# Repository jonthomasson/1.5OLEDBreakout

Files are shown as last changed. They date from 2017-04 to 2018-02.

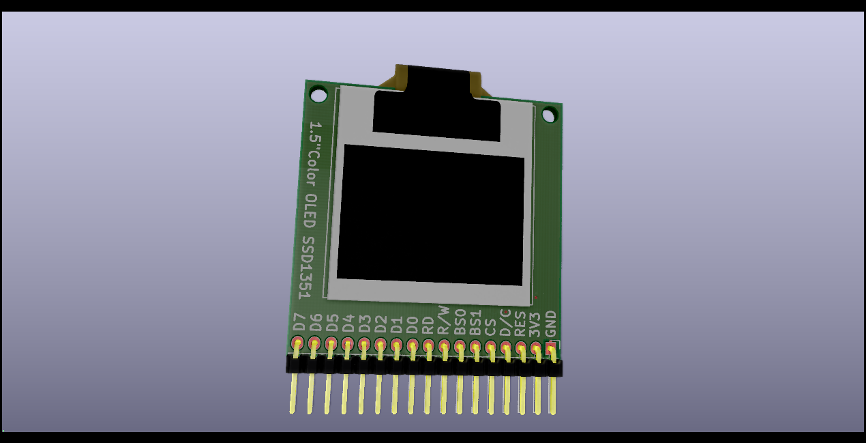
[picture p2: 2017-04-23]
rev1.c/OLED_1.5_128X128_breakout.png

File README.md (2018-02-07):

# 1.5OLEDBreakout
1.5" OLED Breakout SSD1351

Who doesn't love OLED's? Their relatively low power requirements as well as vibrant color displays are alluring to the hacker. While working on a few projects recently I had the need to interface with one of these OLED displays. There didn't seem to be any breakout boards that broke out the parallel interface pins of the controller, so I decided to make my own.

Scouring the internet for a decent OLED display, I came across this one from buydisplay.com. It's a 128x128 RGB display, with 1.5" diagonal measurement. The controller, SSD1351, supports a 8, 16, or 18 bit parallel interface, as well as SPI for communications. It seemed perfect for the projects I had in mind. Most breakout boards out there only take advantage of the SPI pins of the controller, and at least one of my projects would require access to the parallel interface, so I decided to just build my own board to suite my needs. Hopefully someone else finds it useful.

After tying BS0 and BS1 to ground to enable SPI, I tested the OLED with the [adafruit  SSD1351 driver library](https://github.com/adafruit/Adafruit-SSD1351-library).

![OLED Breakout running test program from Adafruit SSD1351 library](https://lh3.googleusercontent.com/MsKkN0FBhNv1MBZHOAWehuTeS2_8jIe-vTxg2sqLBS44pNBJPy4iuyDUc9Usf4BQjBpzPWWo7Bnqe3NkQCG8paahzHArL8N2OJRp6vAqdoAcOqIph1lTVyudKYCDfX7VTnM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)

![enter image description here](https://lh3.googleusercontent.com/N4O0tLOCn0Eo37ZxnNt6EblDyE1QjhN_yxB5joiKvIgpHKnZqY0Tt5LPPp8S8s6vpi8v4A9ziG02BMIxa5gTNILQGj3B6yaHgSGacTQC9WjqcnNdZdKckPPqEXiD1Bdt_oR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)

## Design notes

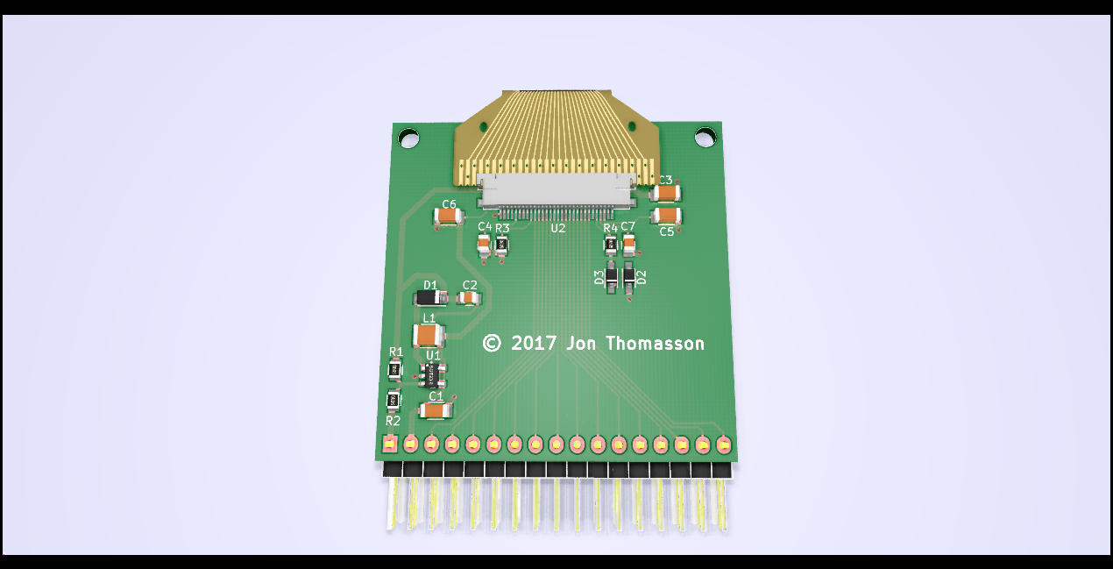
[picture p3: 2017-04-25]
rev1.c/OLED_1.5_128X128_breakout_back.png

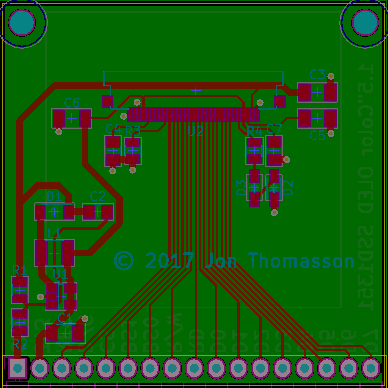
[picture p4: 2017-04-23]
rev1.c/OLED_pcb.PNG

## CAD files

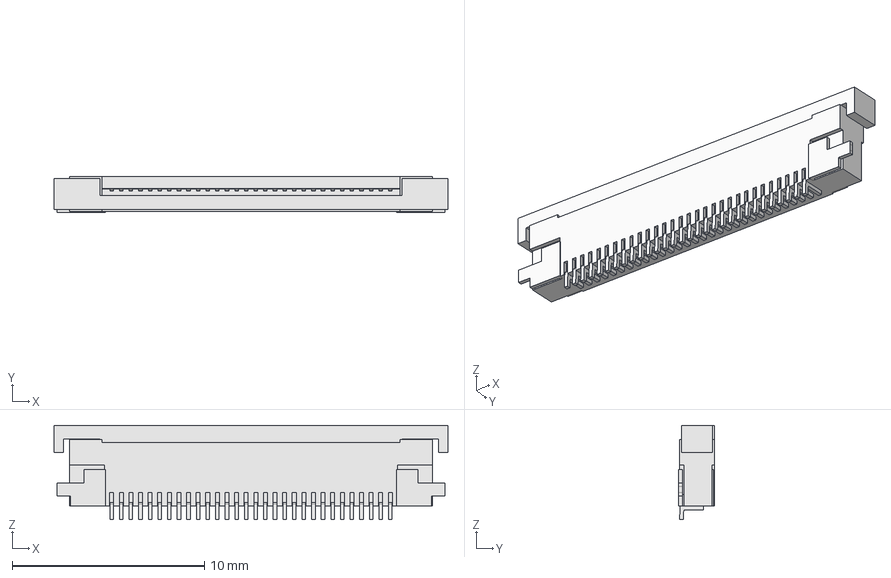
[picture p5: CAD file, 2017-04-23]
rev1.c/3dmodels/SFV30R.step
20.5 x 1.87 x 4.90 mm

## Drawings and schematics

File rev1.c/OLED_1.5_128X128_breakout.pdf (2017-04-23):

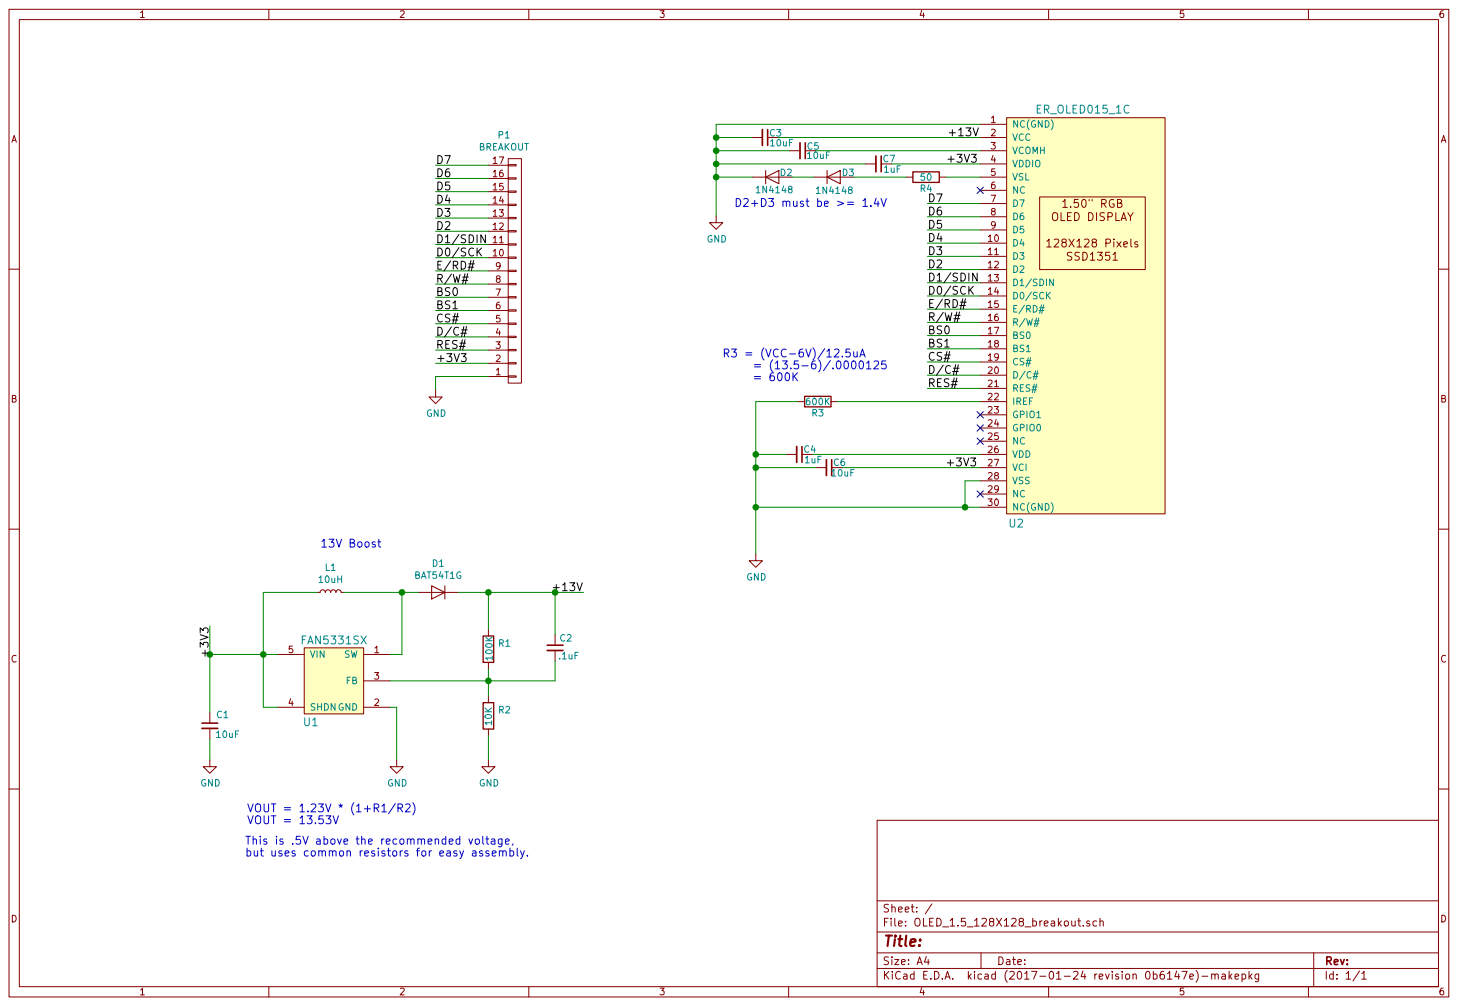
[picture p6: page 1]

VOUT = 13.53V
This is .5V above the recommended voltage,
but uses common resistors for easy assembly.

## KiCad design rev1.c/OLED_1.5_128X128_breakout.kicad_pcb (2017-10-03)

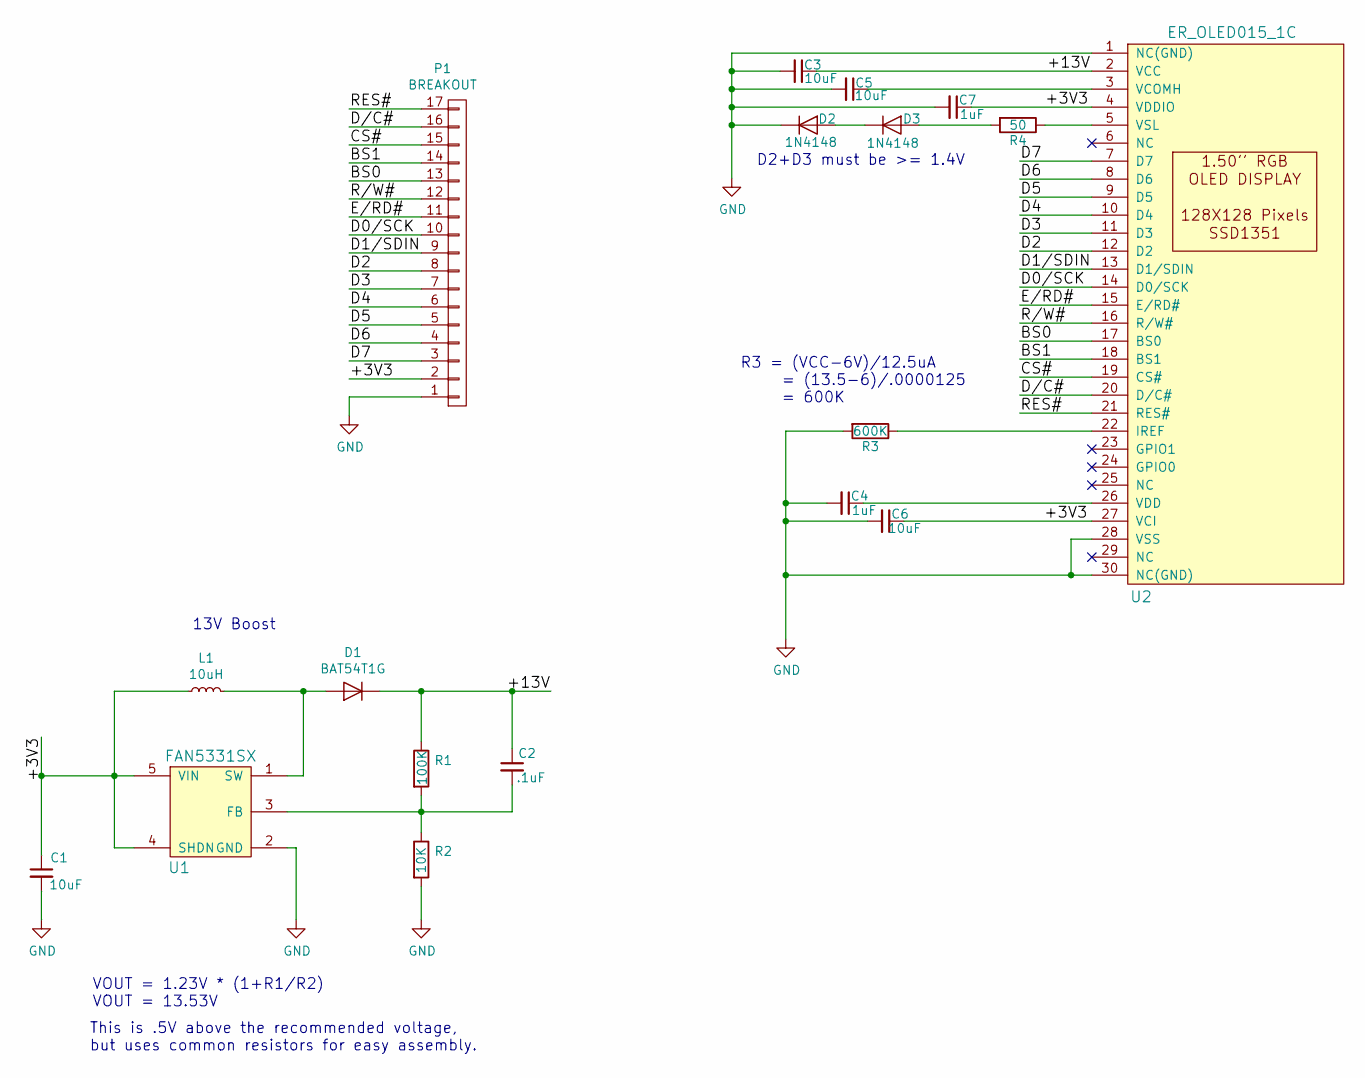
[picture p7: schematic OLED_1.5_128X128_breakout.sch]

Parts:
C1, C3, C5, C6: 10uF; C_1206
C2: .1uF; C_0805
C4, C7: 1uF; C_0805
D1: BAT54T1G; SOD-123
D2, D3: 1N4148; SOD-323
L1: 10uH; C_1210
P1: BREAKOUT; Pin_Header_Angled_1x17
R1: 100K; R_0805
R2: 10K; R_0805
R3: 600K; R_0805
R4: 50; R_0805
U1: FAN5331SX; SOT-23-5
U2: ER_OLED015_1C; CONNECTORS_FPC_SFV30R_4STBE1HLF

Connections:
/+3V3: C1.1, C6.1, C7.1, L1.1, P1.2, U1.4 (SHDN), U1.5 (VIN), U2.4 (VDDIO), U2.27 (VCI)
/+13V: C2.1, C3.1, D1.1 (K), R1.1, U2.2 (VCC)
/BS0: P1.13, U2.17 (BS0)
/BS1: P1.14, U2.18 (BS1)
/CS#: P1.15, U2.19 (CS#)
/D0/SCK: P1.10, U2.14 (D0/SCK)
/D1/SDIN: P1.9, U2.13 (D1/SDIN)
/D2: P1.8, U2.12 (D2)
/D3: P1.7, U2.11 (D3)
/D4: P1.6, U2.10 (D4)
/D5: P1.5, U2.9 (D5)
/D6: P1.4, U2.8 (D6)
/D7: P1.3, U2.7 (D7)
/D/C#: P1.16, U2.20 (D/C#)
/E/RD#: P1.11, U2.15 (E/RD#)
/R/W#: P1.12, U2.16 (R/W#)
/RES#: P1.17, U2.21 (RES#)
GND: C1.2, C3.2, C4.2, C5.2, C6.2, C7.2, D2.1 (K), P1.1, R2.2, R3.2, U1.2 (GND), U2.1 (NC(GND)), U2.28 (VSS), U2.30 (NC(GND))
unnamed: C2.2, R1.2, R2.1, U1.3 (FB)
unnamed: C4.1, U2.26 (VDD)
unnamed: C5.1, U2.3 (VCOMH)
unnamed: D1.2 (A), L1.2, U1.1 (SW)
unnamed: D2.2 (A), D3.1 (K)
unnamed: D3.2 (A), R4.2
unnamed: R3.1, U2.22 (IREF)
unnamed: R4.1, U2.5 (VSL)

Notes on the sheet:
D2+D3 must be >= 1.4V
R3 = (VCC-6V)/12.5uA = (13.5-6)/.0000125 = 600K
13V Boost
VOUT = 1.23V * (1+R1/R2) VOUT = 13.53V
This is .5V above the recommended voltage, but uses common resistors for easy assembly.

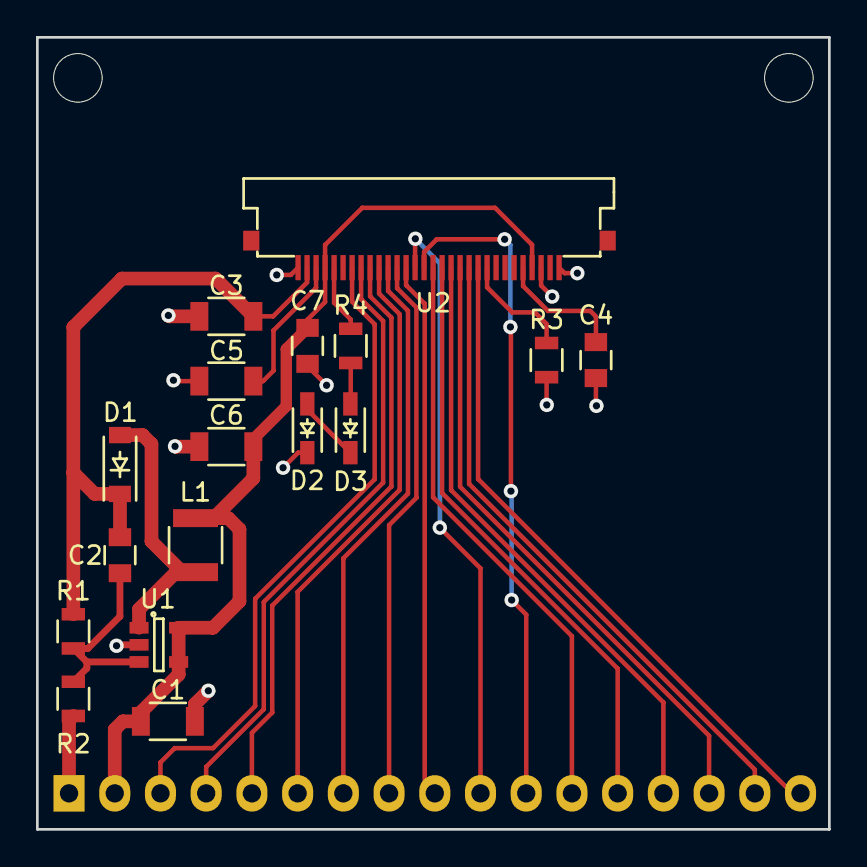
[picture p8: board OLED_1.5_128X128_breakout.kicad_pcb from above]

Board: 2 copper layers, 44.0 x 44.0 mm, 18 parts (1 on the bottom side), 26 nets.

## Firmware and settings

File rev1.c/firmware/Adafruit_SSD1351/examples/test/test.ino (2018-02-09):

/*************************************************** 
  This is a example sketch demonstrating graphic drawing
  capabilities of the SSD1351 library for the 1.5" 
  and 1.27" 16-bit Color OLEDs with SSD1351 driver chip

  Pick one up today in the adafruit shop!
  ------> http://www.adafruit.com/products/1431
  ------> http://www.adafruit.com/products/1673
 
  If you're using a 1.27" OLED, change SSD1351HEIGHT in Adafruit_SSD1351.h
 	to 96 instead of 128

  These displays use SPI to communicate, 4 or 5 pins are required to  
  interface
  Adafruit invests time and resources providing this open source code, 
  please support Adafruit and open-source hardware by purchasing 
  products from Adafruit!

  Written by Limor Fried/Ladyada for Adafruit Industries.  
  BSD license, all text above must be included in any redistribution

  The Adafruit GFX Graphics core library is also required
  https://github.com/adafruit/Adafruit-GFX-Library
  Be sure to install it!
 ****************************************************/

// You can use any (4 or) 5 pins 
#define sclk 2
#define mosi 3
#define dc   4
#define cs   5
#define rst  6

// Color definitions
#define	BLACK           0x0000
#define	BLUE            0x001F
#define	RED             0xF800
#define	GREEN           0x07E0
#define CYAN            0x07FF
#define MAGENTA         0xF81F
#define YELLOW          0xFFE0  
#define WHITE           0xFFFF

#include <Adafruit_GFX.h>
#include <Adafruit_SSD1351.h>
#include <SPI.h>

// Option 1: use any pins but a little slower
Adafruit_SSD1351 tft = Adafruit_SSD1351(cs, dc, mosi, sclk, rst);  

// Option 2: must use the hardware SPI pins 
// (for UNO thats sclk = 13 and sid = 11) and pin 10 must be 
// an output. This is much faster - also required if you want
// to use the microSD card (see the image drawing example)
//Adafruit_SSD1351 tft = Adafruit_SSD1351(cs, dc, rst);

float p = 3.1415926;

void fillpixelbypixel(uint16_t color) {
  for (uint8_t x=0; x < tft.width(); x++) {
    for (uint8_t y=0; y < tft.height(); y++) {
      tft.drawPixel(x, y, color);
    }
  }
  delay(100);
}

void setup(void) {
  Serial.begin(9600);
  Serial.print("hello!");
  tft.begin();

  Serial.println("init");

  // You can optionally rotate the display by running the line below.
  // Note that a value of 0 means no rotation, 1 means 90 clockwise,
  // 2 means 180 degrees clockwise, and 3 means 270 degrees clockwise.
  //tft.setRotation(1);
  // NOTE: The test pattern at the start will NOT be rotated!  The code
  // for rendering the test pattern talks directly to the display and
  // ignores any rotation.

  uint16_t time = millis();
  tft.fillRect(0, 0, 128, 128, BLACK);
  time = millis() - time;
  
  Serial.println(time, DEC);
  delay(500);
  
  lcdTestPattern();
  delay(500);
  
  tft.invert(true);
  delay(100);
  tft.invert(false);
  delay(100);

  tft.fillScreen(BLACK);
  testdrawtext("Lorem ipsum dolor sit amet, consectetur adipiscing elit. Curabitur adipiscing ante sed nibh tincidunt feugiat. Maecenas enim massa, fringilla sed malesuada et, malesuada sit amet turpis. Sed porttitor neque ut ante pretium vitae malesuada nunc bibendum. Nullam aliquet ultrices massa eu hendrerit. Ut sed nisi lorem. In vestibulum purus a tortor imperdiet posuere. ", WHITE);
  delay(500);

  // tft print function!
  tftPrintTest();
  delay(500);
  
  //a single pixel
  tft.drawPixel(tft.width()/2, tft.height()/2, GREEN);
  delay(500);

  // line draw test
  testlines(YELLOW);
  delay(500);    
 
  // optimized lines
  testfastlines(RED, BLUE);
  delay(500);    


  testdrawrects(GREEN);
  delay(1000);

  testfillrects(YELLOW, MAGENTA);
  delay(1000);

  tft.fillScreen(BLACK);
  testfillcircles(10, BLUE);
  testdrawcircles(10, WHITE);
  delay(1000);
   
  testroundrects();
  delay(500);
  
  testtriangles();
  delay(500);
  
  Serial.println("done");
  delay(1000);
}

void loop() {
}

void testlines(uint16_t color) {
   tft.fillScreen(BLACK);
   for (uint16_t x=0; x < tft.width()-1; x+=6) {
     tft.drawLine(0, 0, x, tft.height()-1, color);
   }
   for (uint16_t y=0; y < tft.height()-1; y+=6) {
     tft.drawLine(0, 0, tft.width()-1, y, color);
   }
   
   tft.fillScreen(BLACK);
   for (uint16_t x=0; x < tft.width()-1; x+=6) {
     tft.drawLine(tft.width()-1, 0, x, tft.height()-1, color);
   }
   for (uint16_t y=0; y < tft.height()-1; y+=6) {
     tft.drawLine(tft.width()-1, 0, 0, y, color);
   }
   
   tft.fillScreen(BLACK);
   for (uint16_t x=0; x < tft.width()-1; x+=6) {
     tft.drawLine(0, tft.height()-1, x, 0, color);
   }
   for (uint16_t y=0; y < tft.height()-1; y+=6) {
     tft.drawLine(0, tft.height()-1, tft.width()-1, y, color);
   }

   tft.fillScreen(BLACK);
   for (uint16_t x=0; x < tft.width()-1; x+=6) {
     tft.drawLine(tft.width()-1, tft.height()-1, x, 0, color);
   }
   for (uint16_t y=0; y < tft.height()-1; y+=6) {
     tft.drawLine(tft.width()-1, tft.height()-1, 0, y, color);
   }
   
}

void testdrawtext(char *text, uint16_t color) {
  tft.setCursor(0,0);
  tft.setTextColor(color);
  tft.print(text);
}

void testfastlines(uint16_t color1, uint16_t color2) {
   tft.fillScreen(BLACK);
   for (uint16_t y=0; y < tft.height()-1; y+=5) {
     tft.drawFastHLine(0, y, tft.width()-1, color1);
   }
   for (uint16_t x=0; x < tft.width()-1; x+=5) {
     tft.drawFastVLine(x, 0, tft.height()-1, color2);
   }
}

void testdrawrects(uint16_t color) {
 tft.fillScreen(BLACK);
 for (uint16_t x=0; x < tft.height()-1; x+=6) {
   tft.drawRect((tft.width()-1)/2 -x/2, (tft.height()-1)/2 -x/2 , x, x, color);
 }
}

void testfillrects(uint16_t color1, uint16_t color2) {
 tft.fillScreen(BLACK);
 for (uint16_t x=tft.height()-1; x > 6; x-=6) {
   tft.fillRect((tft.width()-1)/2 -x/2, (tft.height()-1)/2 -x/2 , x, x, color1);
   tft.drawRect((tft.width()-1)/2 -x/2, (tft.height()-1)/2 -x/2 , x, x, color2);
 }
}

void testfillcircles(uint8_t radius, uint16_t color) {
  for (uint8_t x=radius; x < tft.width()-1; x+=radius*2) {
    for (uint8_t y=radius; y < tft.height()-1; y+=radius*2) {
      tft.fillCircle(x, y, radius, color);
    }
  }  
}

void testdrawcircles(uint8_t radius, uint16_t color) {
  for (uint8_t x=0; x < tft.width()-1+radius; x+=radius*2) {
    for (uint8_t y=0; y < tft.height()-1+radius; y+=radius*2) {
      tft.drawCircle(x, y, radius, color);
    }
  }  
}

void testtriangles() {
  tft.fillScreen(BLACK);
  int color = 0xF800;
  int t;
  int w = tft.width()/2;
  int x = tft.height();
  int y = 0;
  int z = tft.width();
  for(t = 0 ; t <= 15; t+=1) {
    tft.drawTriangle(w, y, y, x, z, x, color);
    x-=4;
    y+=4;
    z-=4;
    color+=100;
  }
}

void testroundrects() {
  tft.fillScreen(BLACK);
  int color = 100;
  
  int x = 0;
  int y = 0;
  int w = tft.width();
  int h = tft.height();
  for(int i = 0 ; i <= 24; i++) {
    tft.drawRoundRect(x, y, w, h, 5, color);
    x+=2;
    y+=3;
    w-=4;
    h-=6;
    color+=1100;
    Serial.println(i);
  }
}

void tftPrintTest() {
  tft.fillScreen(BLACK);
  tft.setCursor(0, 5);
  tft.setTextColor(RED);  
  tft.setTextSize(1);
  tft.println("Hello World!");
  tft.setTextColor(YELLOW);
  tft.setTextSize(2);
  tft.println("Hello World!");
  tft.setTextColor(BLUE);
  tft.setTextSize(3);
  tft.print(1234.567);
  delay(1500);
  tft.setCursor(0, 5);
  tft.fillScreen(BLACK);
  tft.setTextColor(WHITE);
  tft.setTextSize(0);
  tft.println("Hello World!");
  tft.setTextSize(1);
  tft.setTextColor(GREEN);
  tft.print(p, 6);
  tft.println(" Want pi?");
  tft.println(" ");
  tft.print(8675309, HEX); // print 8,675,309 out in HEX!
  tft.println(" Print HEX!");
  tft.println(" ");
  tft.setTextColor(WHITE);
  tft.println("Sketch has been");
  tft.println("running for: ");
  tft.setTextColor(MAGENTA);
  tft.print(millis() / 1000);
  tft.setTextColor(WHITE);
  tft.print(" seconds.");
}

void mediabuttons() {
 // play
  tft.fillScreen(BLACK);
  tft.fillRoundRect(25, 10, 78, 60, 8, WHITE);
  tft.fillTriangle(42, 20, 42, 60, 90, 40, RED);
  delay(500);
  // pause
  tft.fillRoundRect(25, 90, 78, 60, 8, WHITE);
  tft.fillRoundRect(39, 98, 20, 45, 5, GREEN);
  tft.fillRoundRect(69, 98, 20, 45, 5, GREEN);
  delay(500);
  // play color
  tft.fillTriangle(42, 20, 42, 60, 90, 40, BLUE);
  delay(50);
  // pause color
  tft.fillRoundRect(39, 98, 20, 45, 5, RED);
  tft.fillRoundRect(69, 98, 20, 45, 5, RED);
  // play color
  tft.fillTriangle(42, 20, 42, 60, 90, 40, GREEN);
}

/**************************************************************************/
/*! 
    @brief  Renders a simple test pattern on the LCD
*/
/**************************************************************************/
void lcdTestPattern(void)
{
  uint32_t i,j;
  tft.goTo(0, 0);
  
  for(i=0;i<128;i++)
  {
    for(j=0;j<128;j++)
    {
      if(i<16){
        tft.writeData(RED>>8); tft.writeData(RED);
      }
      else if(i<32) {
        tft.writeData(YELLOW>>8);tft.writeData(YELLOW);
      }
      else if(i<48){tft.writeData(GREEN>>8);tft.writeData(GREEN);}
      else if(i<64){tft.writeData(CYAN>>8);tft.writeData(CYAN);}
      else if(i<80){tft.writeData(BLUE>>8);tft.writeData(BLUE);}
      else if(i<96){tft.writeData(MAGENTA>>8);tft.writeData(MAGENTA);}
      else if(i<112){tft.writeData(BLACK>>8);tft.writeData(BLACK);}
      else {
        tft.writeData(WHITE>>8);      
        tft.writeData(WHITE);
       }
    }
  }
}

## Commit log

2017-04-23 initial checkin
    [OLED_1.5_128X128_breakout-B.Cu.gbl, OLED_1.5_128X128_breakout-B.Mask.gbs, OLED_1.5_128X128_breakout-B.SilkS.gbo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]
2017-04-25 added rev 1.b with better routing around L1.
    [OLED_1.5_128X128_breakout-B.Cu.gbl, OLED_1.5_128X128_breakout-B.Mask.gbs, OLED_1.5_128X128_breakout-B.SilkS.gbo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]
2017-10-01 fixing connector
    [OLED_1.5_128X128_breakout-B.Cu.gbl, OLED_1.5_128X128_breakout-B.Mask.gbs, OLED_1.5_128X128_breakout-B.SilkS.gbo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]
2017-10-03 finished routing rev 1.c
    [OLED_1.5_128X128_breakout.kicad_pcb, OLED_1.5_128X128_breakout.sch]
2017-10-03 finished silk screen and created gerbers
    [OLED_1.5_128X128_breakout-B.Cu.gbl, OLED_1.5_128X128_breakout-B.Mask.gbs, OLED_1.5_128X128_breakout-B.SilkS.gbo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]
2017-10-03 efficiency check and new gerbers
    [OLED_1.5_128X128_breakout-B.Cu.gbl, OLED_1.5_128X128_breakout-B.Mask.gbs, OLED_1.5_128X128_breakout-B.SilkS.gbo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]
